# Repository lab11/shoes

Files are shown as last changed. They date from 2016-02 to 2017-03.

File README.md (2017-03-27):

Shoes!
======

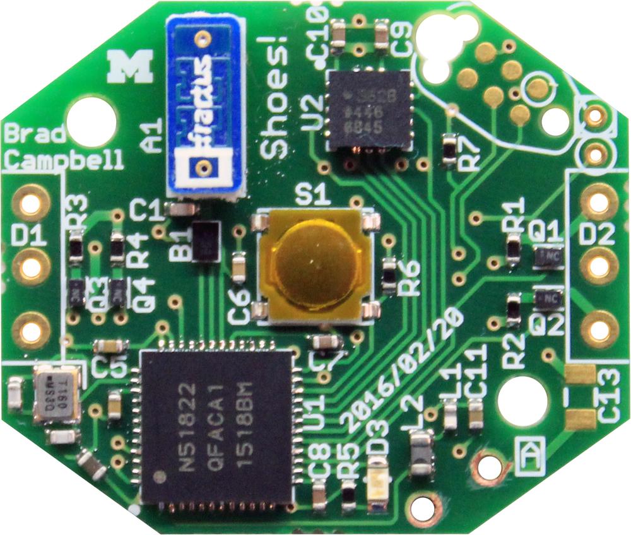
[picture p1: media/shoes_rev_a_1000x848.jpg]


BLE + shoelaces

Cloning This Repo
-----------------

When cloning this git repo, be sure to do so with submodules. The software
for this project depends on [nrf5x-base](https://github.com/lab11/nrf5x-base),
and to make sure you have the correct version of that repository, you need
to ensure that the submodule is checked out.

    git clone --recursive https://github.com/lab11/shoes.git

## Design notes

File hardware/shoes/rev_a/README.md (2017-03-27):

Shoes HW Rev A
==============

The shoes hardware PCB consists of:
- A Nordic nRF51822
- Two 2 color thru-hole LEDs
- A center push button
- An ADXL362 accelerometer

The nRF51822 BLE radio and processor is programmable over JTAG using the JLink JLinkExe program.
More information about programming the nRF51822 can he found
[here](https://github.com/lab11/nrf5x-base#program-a-nrf51822).

PCB Files
---------

The PCB was designed in [Eagle](http://www.autodesk.com/products/eagle/overview)
(version 6, but it should work in newer versions too.
Also committed are the gerbers that were used to manufacturer the first
revision of the boards.

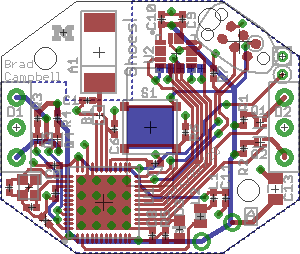
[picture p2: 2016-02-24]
hardware/shoes/rev_a/shoes_pcb.png

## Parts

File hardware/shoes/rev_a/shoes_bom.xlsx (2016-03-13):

Qty | Value | Device | Package | Parts | Description | DIGIKEY | MOUSER | NEWARK | RICHARDSON_RFPD |  | Quantity: |  | 100 | Quantity: |  | 250 | Quantity: |  | 400
1 | FRACTUS-2.4GHZ-FR05-S1-N-0-102 | FRACTUS-2.4GHZ-FR05-S1-N-0-102 | FRACTUS-ANTENNA-FR05-S1-N-0-102 | A1 | Fractus Compact Reach XtendTM chip antenna is engineered specifically for Bluetooth, |  |  |  | FR05-S1-N-0102B |  | 1 | 1 |  | 0.78 | 0.78 |  | 0.7 | 0.7
1 | BAL-NRF01D3 | BAL-NRF01D3 | BAL-NRF01D3 | B1 | 50 ohm nominal input / conjugate match balun to nRF51422-QFAA, | 497-13637-1-ND | 511-BAL-NRF01D3 |  |  |  | 0.52 | 0.52 |  | 0.52 | 0.52 |  | 0.52 | 0.52
1 | 0.8pF | CAPACITOR | 0402_CAP | C1 | 0402 Capacitor | 490-6269-1-ND |  |  |  |  | 0.0325 | 0.0325 |  | 0.02656 | 0.02656 |  | 0.02656 | 0.02656
2 | 12pF | CAPACITOR | 0402_CAP | C2, C3 | 0402 Capacitor | 490-6197-1-ND |  |  |  |  | 0.0198 | 0.0396 |  | 0.0162 | 0.0324 |  | 0.0162 | 0.0324
2 | 1nF | CAPACITOR | 0402_CAP | C4, C5 | 0402 Capacitor | 490-1303-1-ND |  |  |  |  | 0.0057 | 0.0114 |  | 0.00464 | 0.00928 |  | 0.00464 | 0.00928
1 | 2.2nF | CAPACITOR | 0402_CAP | C6 | 0402 Capacitor | 490-5419-1-ND |  |  |  |  | 0.0105 | 0.0105 |  | 0.00856 | 0.00856 |  | 0.00856 | 0.00856
1 | 47nF | CAPACITOR | 0402_CAP | C7 | 0402 Capacitor | 445-1264-1-ND |  |  |  |  | 0.0149 | 0.0149 |  | 0.01216 | 0.01216 |  | 0.01216 | 0.01216
3 | 0.1uF | CAPACITOR | 0402_CAP | C8, C9, C10 | 0402 Capacitor | 445-4952-1-ND |  |  |  |  | 0.0121 | 0.0363 |  | 0.00992 | 0.02976 |  | 0.00992 | 0.02976
1 | 1uF | CAPACITOR | 0402_CAP | C11 | 0402 Capacitor | 1276-1513-1-ND |  |  |  |  | 0.084 | 0.084 |  | 0.084 | 0.084 |  | 0.084 | 0.084
1 | 4.7uF | CAPACITOR | 0402_CAP | C12 | 0402 Capacitor | 445-5947-1-ND |  |  |  |  | 0.175 | 0.175 |  | 0.14 | 0.14 |  | 0.14 | 0.14
2 | BICOLOR-THRUHOLE | BICOLOR-THRUHOLE | 3AXIS-0.1IN | D1, D2 | 3 axis thru-hold LED |  |  |  |  |  | 1.28 | 2.56 |  | 1.18 | 2.36 |  | 0.98 | 1.96
1 | BLUE | LED0603 | LED-0603 | D3 | LEDs | 160-1837-1-ND |  |  |  |  | 0.1797 | 0.1797 |  | 0.12712 | 0.12712 |  | 0.12712 | 0.12712
1 | 15nH | INDUCTOR0402 | 0402_CAP | L1 |  | 587-1521-1-ND |  |  |  |  | 0.042 | 0.042 |  | 0.039 | 0.039 |  | 0.039 | 0.039
1 | 10uH | INDUCTOR0603 | 0603_CAP | L2 |  | 490-4025-1-ND |  |  |  |  | 0.0907 | 0.0907 |  | 0.08416 | 0.08416 |  | 0.08416 | 0.08416
4 | MOSFET-NCHANNELXFDN-3 | MOSFET-NCHANNELXFDN-3 | XFDFN-3 | Q1, Q2, Q3, Q4 | Generic NMOS footprint | DMN2400UFB4-7DICT-ND |  |  |  |  | 0.1585 | 0.634 |  | 0.1585 | 0.634 |  | 0.1585 | 0.634
4 | 470 | RESISTOR | 0402_RES | R1, R2, R3, R4 | Resistor | RHM470CDCT-ND |  |  |  |  | 0.0116 | 0.0464 |  | 0.00888 | 0.03552 |  | 0.00888 | 0.03552
2 | 1k | RESISTOR | 0402_RES | R5, R6 | Resistor | RHM1.0KCECT-ND |  |  |  |  | 0.0082 | 0.0164 |  | 0.00624 | 0.01248 |  | 0.00624 | 0.01248
1 | 12k | RESISTOR | 0402_RES | R7 | Resistor | RHM12.0KCDCT-ND |  |  |  |  | 0.0116 | 0.0116 |  | 0.00888 | 0.00888 |  | 0.00888 | 0.00888
1 | TL3315NF100Q | TL3315NF100Q | TL3315NF250Q | S1 | SWITCH TACTILE SPST-NO 0.05A 15V | EG4622CT-ND |  |  |  |  | 0.1823 | 0.1823 |  | 0.1716 | 0.1716 |  | 0.1716 | 0.1716
1 | NRF51822QF | NRF51822QF | QFN-48-6MM | U1 | Multiprotocol Bluetooth® 4.0 low energy/2.4 GHz RF SoC | 1490-1042-1-ND | 949-NRF51822-QFAC-R7 |  |  |  | 3.894 | 3.894 |  | 3.54 | 3.54 |  | 3.54 | 3.54
1 | ADXL362 | ADXL362 | TFLGA-16/3.3MMX3.1MM | U2 | IC ACCEL DIG LO PWR 3AX 16LGA | ADXL362BCCZ-RL7CT-ND | 584-ADXL362BCCZ-R7 | 47W0478 |  |  | 6.9018 | 6.9018 |  | 6.9018 | 6.9018 |  | 6.9018 | 6.9018
1 | 16MHz | TXC-8Y | TXC-8Y | X1 | 2mmx1.6mm SMD Crystal | 887-2003-1-ND |  |  |  |  | 0.945 | 0.945 |  | 0.945 | 0.945 |  | 0.945 | 0.945
1 | PCB |  |  |  |  |  |  |  |  |  | 4 | 4 |  | 3.2 | 3.2 |  | 2.5 | 2.5
1 | Assembly |  |  |  |  |  |  |  |  |  | 10 | 10 |  | 9 | 9 |  | 8 | 8
 |  |  |  |  |  |  |  |  |  | Parts Only |  | 17.4281 | $1742.81 |  | 16.50228 | $4125.57 |  | 16.02228 | $6408.91
 |  |  |  |  |  |  |  |  |  | Parts/PCB |  | 21.4281 | $2142.81 |  | 19.70228 | $4925.57 |  | 18.52228 | $7408.91
 |  |  |  |  |  |  |  |  |  | Parts/PCB/Assem |  | 31.4281 | $3142.81 |  | 28.70228 | $7175.57 |  | 26.52228 | $10608.91

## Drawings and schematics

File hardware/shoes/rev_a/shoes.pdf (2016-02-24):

## JTAG Connection

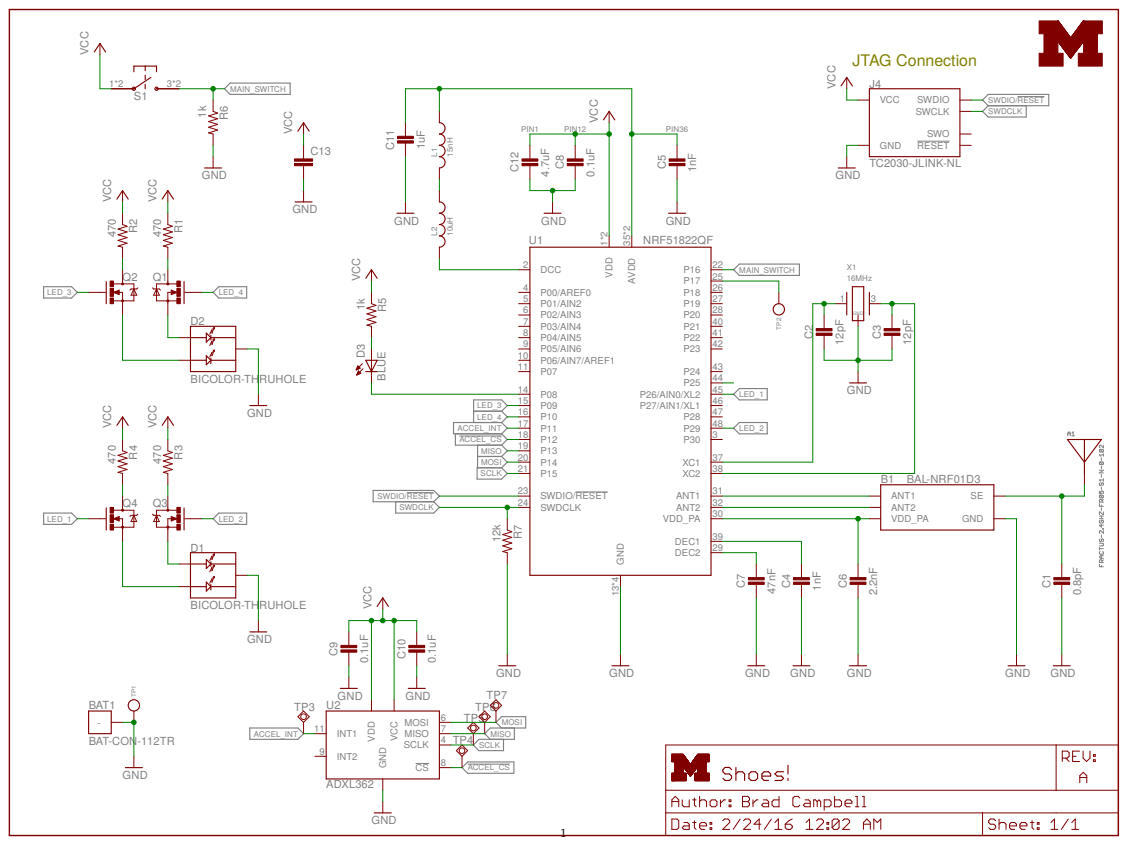
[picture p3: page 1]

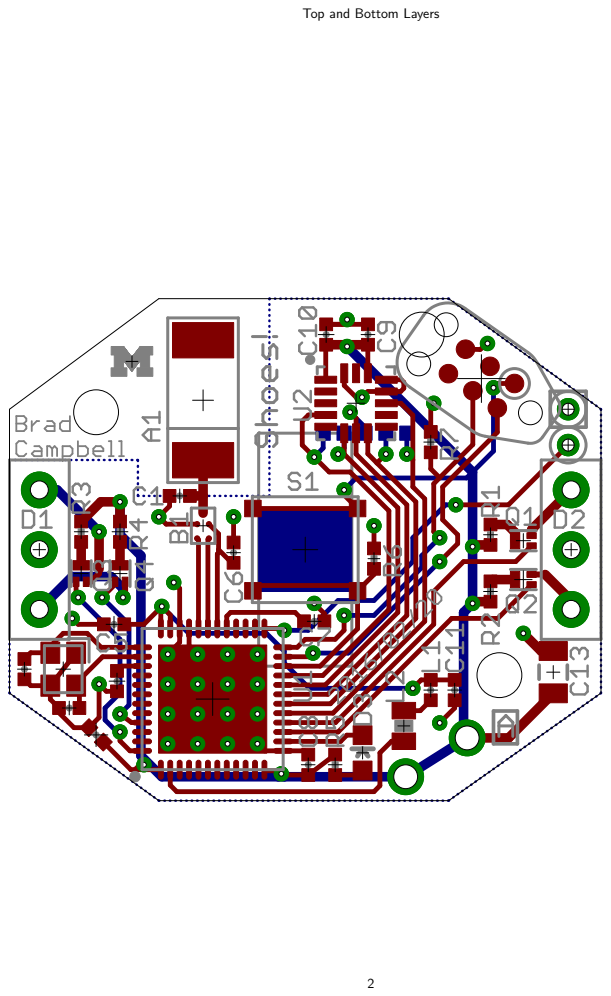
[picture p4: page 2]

Top and Bottom Layers

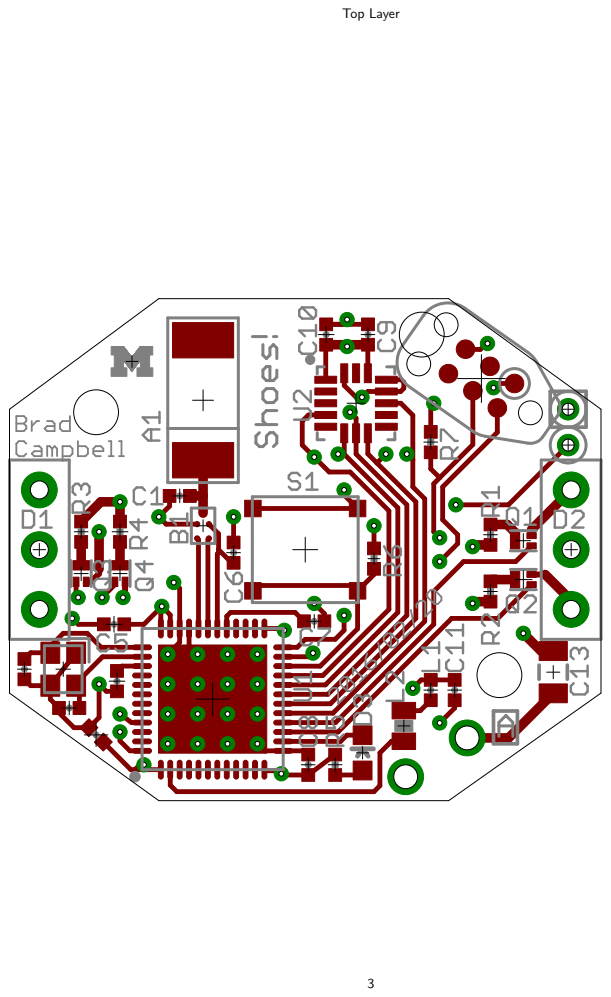
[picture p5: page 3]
Top Layer

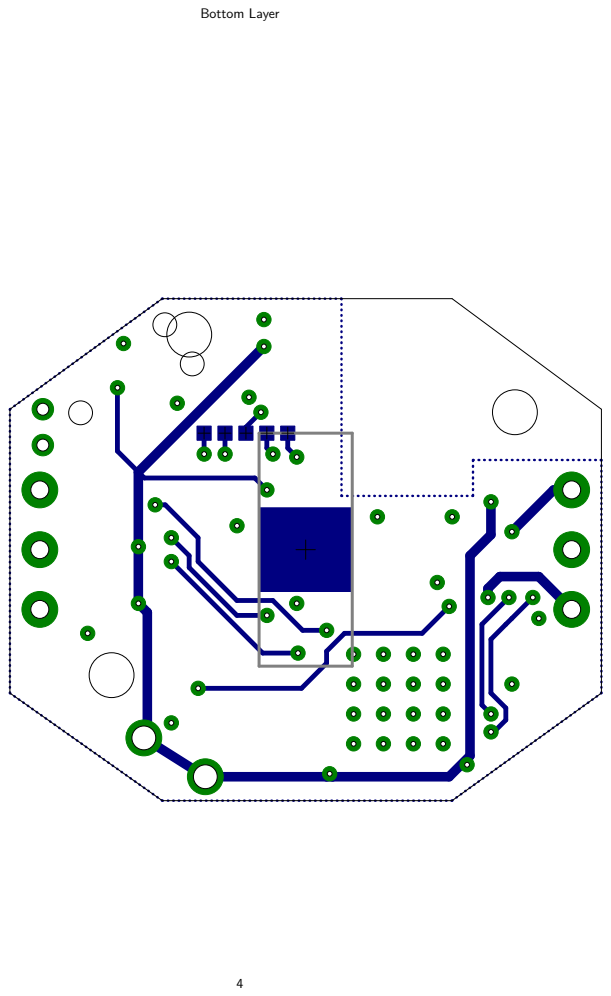
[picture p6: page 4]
Bottom Layer

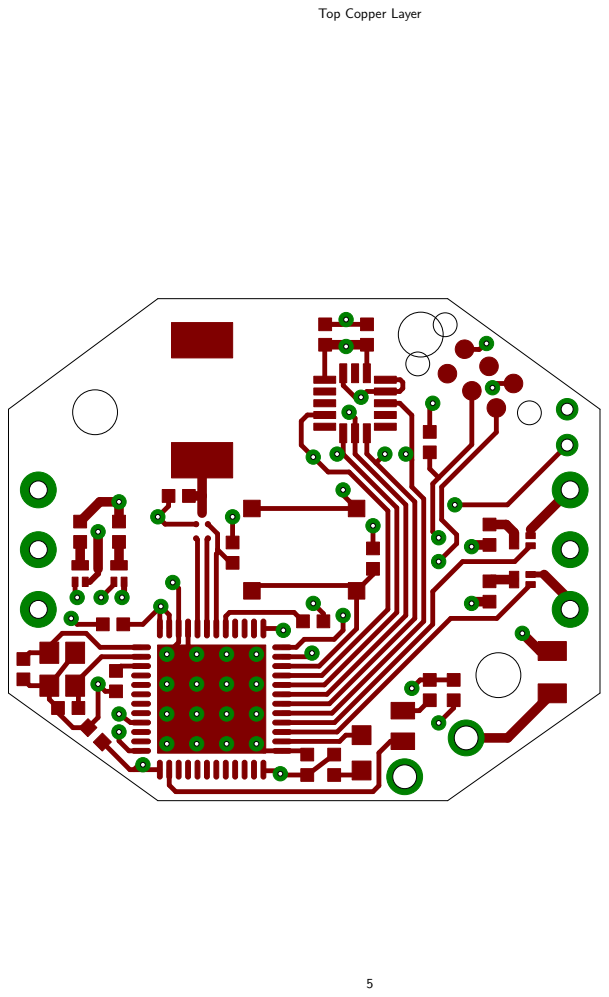
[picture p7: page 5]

Top Copper Layer

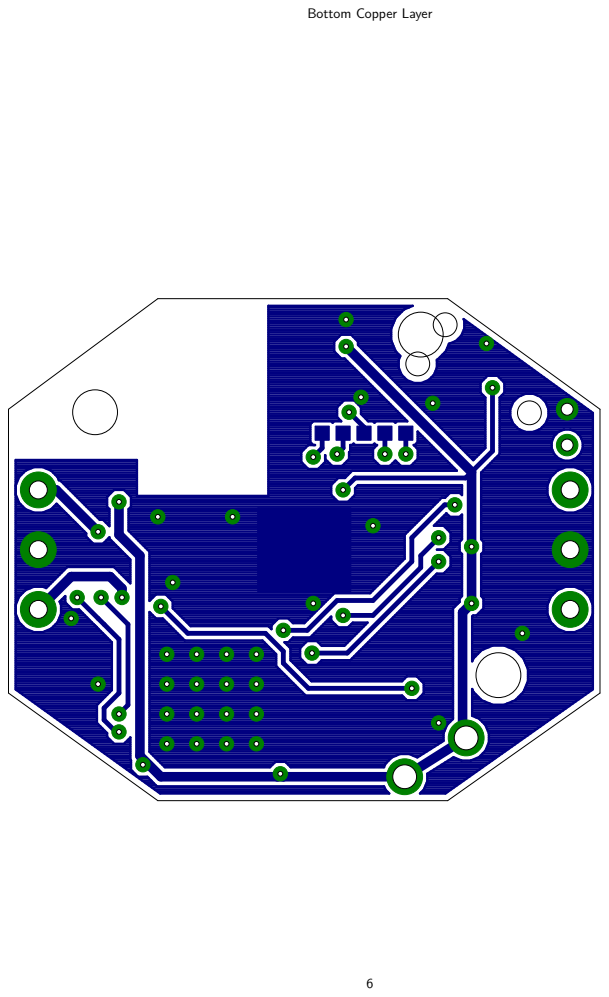
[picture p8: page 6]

Bottom Copper Layer

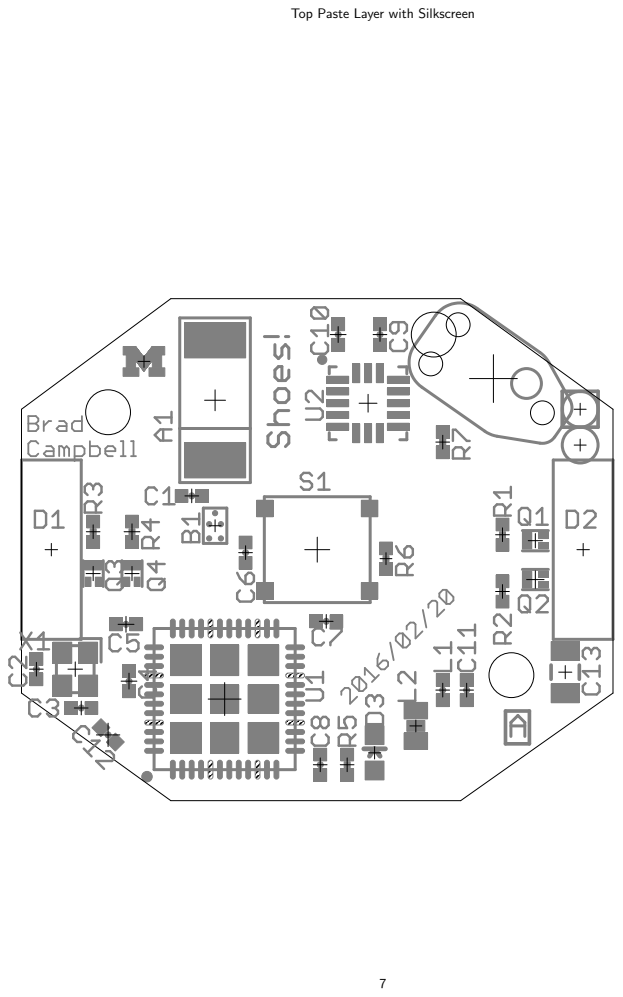
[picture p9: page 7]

Top Paste Layer with Silkscreen

Bottom Paste Layer with Silkscreen

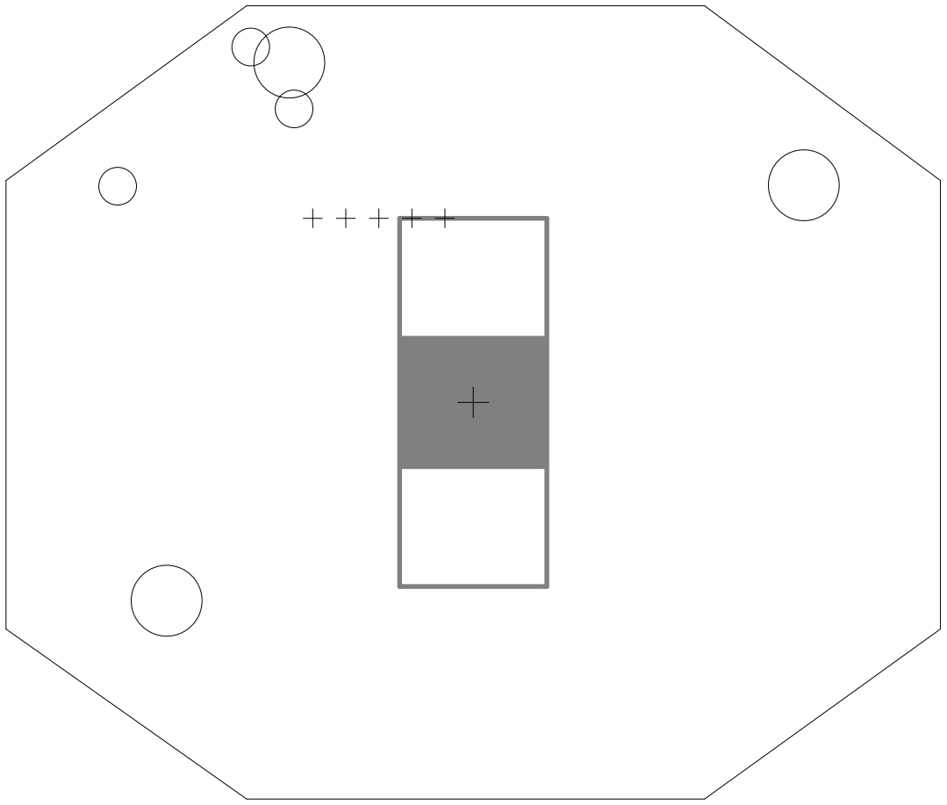
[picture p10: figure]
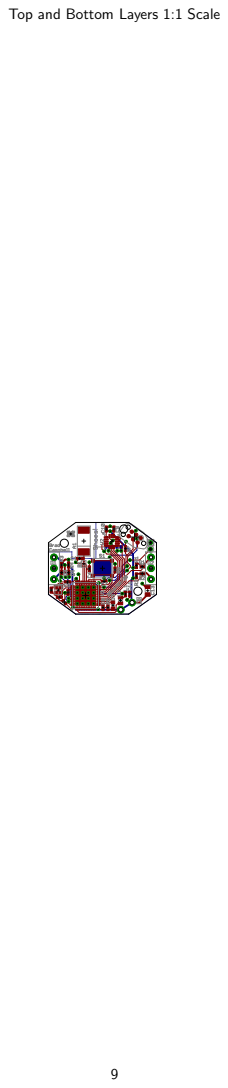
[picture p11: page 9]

Top and Bottom Layers 1:1 Scale

Top Layer 1:1 Scale

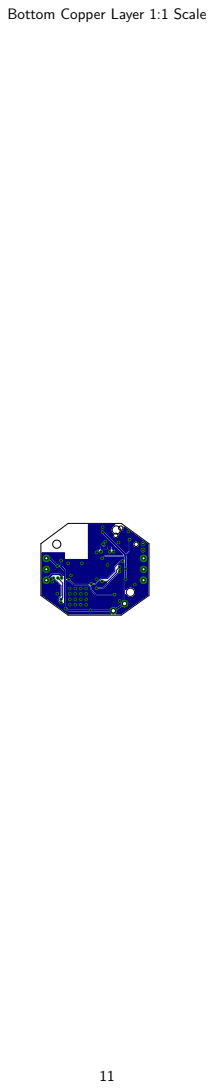
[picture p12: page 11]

Bottom Copper Layer 1:1 Scale

### shoes

Qty Value | Device
1 FRACTUS-2.4GHZ-FR05-S1-N-0-102 FRACTUS-2.4GHZ-FR05-S1-N-0-102
1 BAL-NRF01D3 | BAL-NRF01D3
1 0.8pF | CAPACITOR
2 12pF | CAPACITOR
2 1nF | CAPACITOR
1 2.2nF | CAPACITOR
1 47nF | CAPACITOR
3 0.1uF | CAPACITOR
1 1uF | CAPACITOR
1 4.7uF | CAPACITOR
2 BICOLOR-THRUHOLE | BICOLOR-THRUHOLE
1 BLUE | LED0603
1 15nH | INDUCTOR0402
1 10uH | INDUCTOR0603
4 MOSFET-NCHANNELXFDN-3 | MOSFET-NCHANNELXFDN-3
4 470 | RESISTOR
2 1k | RESISTOR
1 12k | RESISTOR
1 TL3315NF100Q | TL3315NF100Q
1 NRF51822QF | NRF51822QF
1 ADXL362 | ADXL362
1 16MHz | TXC-8Y

### shoes

Package | Parts
FRACTUS-ANTENNA-FR05-S1-N-0-102 A1
BAL-NRF01D3 | B1
0402_CAP | C1
0402_CAP | C2, C3
0402_CAP | C4, C5
0402_CAP | C6
0402_CAP | C7
0402_CAP | C8, C9, C10
0402_CAP | C11
0402_CAP | C12
3AXIS-0.1IN | D1, D2
LED-0603 | D3
0402_CAP | L1
0603_CAP | L2
XFDFN-3 | Q1, Q2, Q3, Q4
0402_RES | R1, R2, R3, R4
0402_RES | R5, R6
0402_RES | R7
TL3315NF100Q | S1
QFN-48-6MM | U1
TFLGA-16/3.3MMX3.1MM | U2
TXC-8Y | X1

### shoes

Description
Fractus Compact Reach XtendTM chip antenna is engineered specifically for Bluetooth, 50 ohm nominal input / conjugate match balun to nRF51422-QFAA,
0402 Capacitor
0402 Capacitor
0402 Capacitor
0402 Capacitor
0402 Capacitor
0402 Capacitor
0402 Capacitor
0402 Capacitor
3 axis thru-hold LED
LEDs

Generic NMOS footprint
Resistor
Resistor
Resistor
SWITCH TACTILE SPST-NO 0.05A 15V Multiprotocol Bluetooth® 4.0 low energy/2.4 GHz RF SoC IC ACCEL DIG LO PWR 3AX 16LGA
2mmx1.6mm SMD Crystal

### shoes

DIGIKEY | MOUSER | NEWARK RICHARDSON_RFPD
| | FR05-S1-N-0102B
497-13637-1-ND | 511-BAL-NRF01D3
490-6269-1-ND
490-6197-1-ND
490-1303-1-ND
490-5419-1-ND
445-1264-1-ND
445-4952-1-ND
1276-1513-1-ND
445-5947-1-ND

587-1521-1-ND
490-4025-1-ND
DMN2400UFB4-7DICT-ND
RHM470CDCT-ND
RHM1.0KCECT-ND
RHM12.0KCDCT-ND
EG4620CT-ND
1490-1042-1-ND | 949-NRF51822-QFAC-R7
ADXL362BCCZ-RL7CT-ND 584-ADXL362BCCZ-R7 47W0478 887-2003-1-ND

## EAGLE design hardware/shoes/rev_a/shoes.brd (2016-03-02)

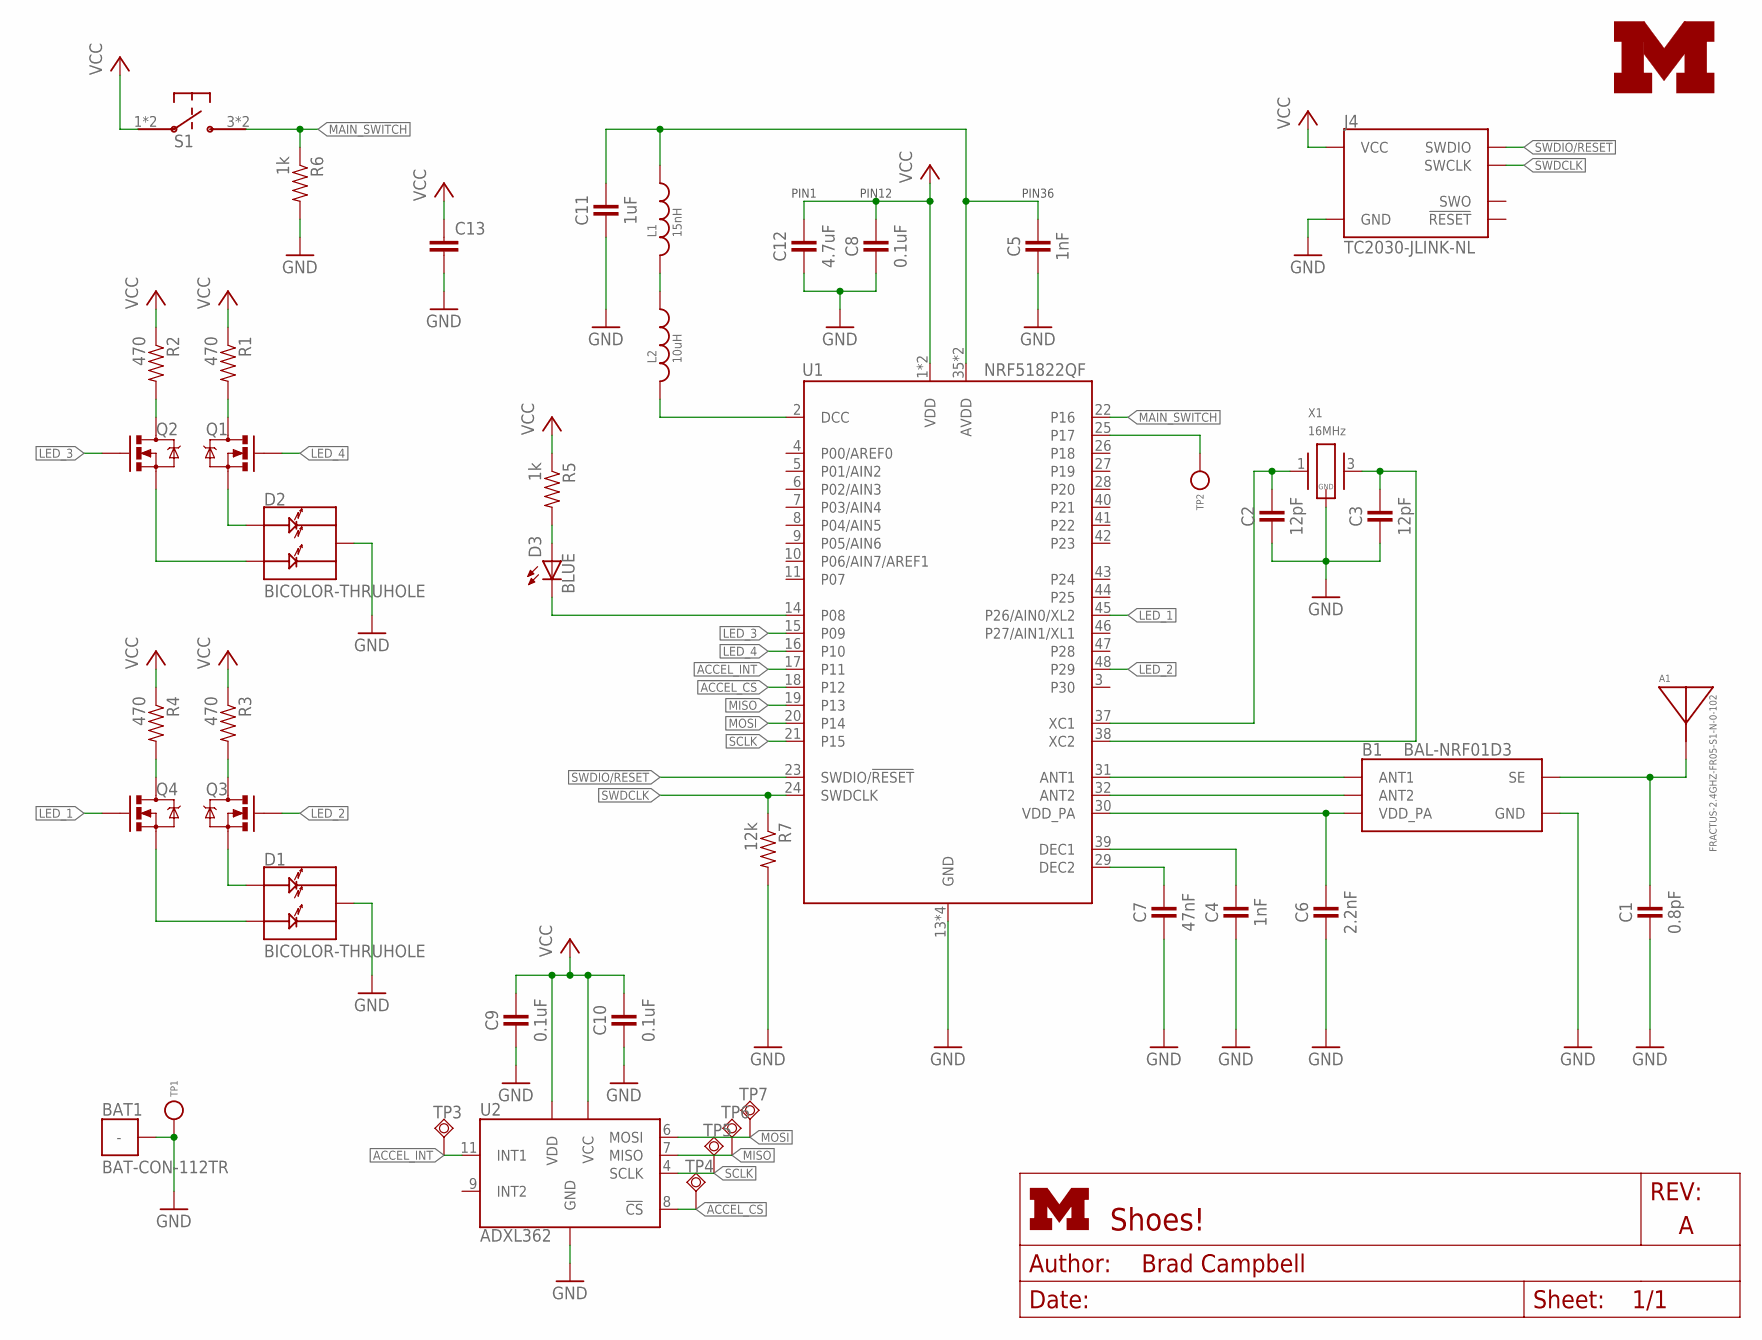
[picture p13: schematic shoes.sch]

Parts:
A1: FRACTUS-2.4GHZ-FR05-S1-N-0-102; FRACTUS-ANTENNA-FR05-S1-N-0-102
B1: BAL-NRF01D3
BAT1: BAT-CON-112TR
C1: 0.8pF; 0402_CAP; DIGIKEY 490-6269-1-ND
C2, C3: 12pF; 0402_CAP; DIGIKEY 490-6197-1-ND
C4, C5: 1nF; 0402_CAP; DIGIKEY 490-1303-1-ND
C6: 2.2nF; 0402_CAP; DIGIKEY 490-5419-1-ND
C7: 47nF; 0402_CAP; DIGIKEY 445-1264-1-ND
C8, C9, C10: 0.1uF; 0402_CAP; DIGIKEY 445-4952-1-ND
C11: 1uF; 0402_CAP; DIGIKEY 1276-1513-1-ND
C12: 4.7uF; 0402_CAP; DIGIKEY 445-5947-1-ND
C13: CAP0805; 0805
D1, D2: BICOLOR-THRUHOLE; 3AXIS-0.1IN
D3: BLUE; LED-0603
J4: TC2030-JLINK-NL; TC2030-IDC-NL
L1: 15nH; 0402_CAP; DIGIKEY 587-1521-1-ND
L2: 10uH; 0603_CAP; DIGIKEY 490-4025-1-ND
LOGO3: UMICH_SOLID_TINY; UMICH_SOLID_50MIL
Q1, Q2, Q3, Q4: MOSFET-NCHANNELXFDN-3; XFDFN-3
R1, R2, R3, R4: 470; 0402_RES; DIGIKEY RHM470CDCT-ND
R5, R6: 1k; 0402_RES; DIGIKEY RHM1.0KCECT-ND
R7: 12k; 0402_RES; DIGIKEY RHM12.0KCDCT-ND
S1: TL3315NF100Q
TP1, TP2: TEST_POINT_0.020IN; TESTPOINT_0.020IN
TP3, TP4, TP5, TP6, TP7: TPSQTP06SQ; TP06SQ
U1: NRF51822QF; QFN-48-6MM
U2: ADXL362; TFLGA-16/3.3MMX3.1MM
X1: 16MHz; TXC-8Y; DIGIKEY 887-2003-1-ND

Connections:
!ACCEL_CS: TP4.TP, U1.18 (P12), U2.8 (!CS)
ACCEL_INT: TP3.TP, U1.17 (P11), U2.11 (INT1)
AVDD: C5.1, C11.1, L1.1, U1.35 (AVDD), U1.36 (AVDD)
DCC: L2.2, U1.2 (DCC)
GND: B1.GND, BAT1.PAD, C1.2, C2.2, C3.2, C4.2, C5.2, C6.2, C7.2, C8.2, C9.2, C10.2, C11.2, C12.2, C13.2, D1.M (C), D2.M (C), J4.5 (GND), R6.2, R7.2, TP1.TESTPOINT, U1.13 (GND), U1.33 (GND), U1.34 (GND), U1.GND, U2.12 (GND), U2.13 (GND), U2.16 (GND), X1.2 (GND), X1.4 (GND)
LED_1: Q4.G, U1.45 (P26/AIN0/XL2)
LED_2: Q3.G, U1.48 (P29)
LED_3: Q2.G, U1.15 (P09)
LED_4: Q1.G, U1.16 (P10)
MAIN_SWITCH: R6.1, S1.3, S1.4, U1.22 (P16)
MISO: TP6.TP, U1.19 (P13), U2.7 (MISO)
MOSI: TP7.TP, U1.20 (P14), U2.6 (MOSI)
unnamed: TP2.TESTPOINT, U1.25 (P17)
unnamed: D2.1 (A1), Q1.S
unnamed: B1.ANT1, U1.31 (ANT1)
unnamed: B1.ANT2, U1.32 (ANT2)
unnamed: D3.C, U1.14 (P08)
unnamed: D2.2 (A2), Q2.S
unnamed: Q2.D, R2.2
unnamed: Q1.D, R1.2
unnamed: A1.1, B1.SE, C1.1
unnamed: D1.1 (A1), Q3.S
unnamed: D1.2 (A2), Q4.S
unnamed: L1.2, L2.1
unnamed: Q4.D, R4.2
unnamed: C2.1, U1.37 (XC1), X1.1
unnamed: C3.1, U1.38 (XC2), X1.3 (2)
unnamed: C4.1, U1.39 (DEC1)
unnamed: C7.1, U1.29 (DEC2)
unnamed: Q3.D, R3.2
unnamed: D3.A, R5.2
SCLK: TP5.TP, U1.21 (P15), U2.4 (SCLK)
SWDCLK: J4.4 (SWCLK), R7.1, U1.24 (SWDCLK)
SWDIO/!RESET: J4.2 (SWDIO), U1.23 (SWDIO/!RESET)
VCC: C8.1, C9.1, C10.1, C12.1, C13.1, J4.1 (VCC), R1.1, R2.1, R3.1, R4.1, R5.1, S1.1, S1.2, U1.1 (VDD), U1.12 (VDD), U2.1 (VDD), U2.14 (VCC)
VDD_PA: B1.VCC (VDD_PA), C6.1, U1.30 (VDD_PA)

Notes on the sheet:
PIN12
PIN1
PIN36

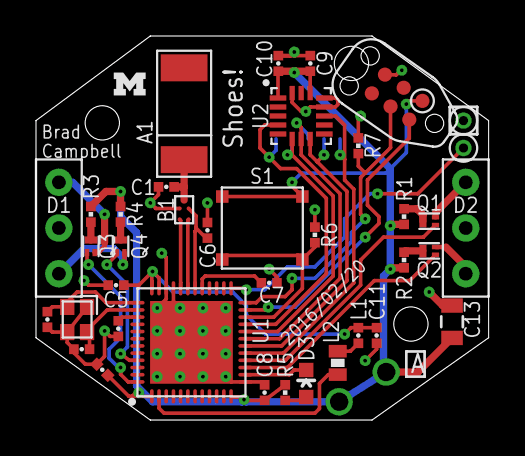
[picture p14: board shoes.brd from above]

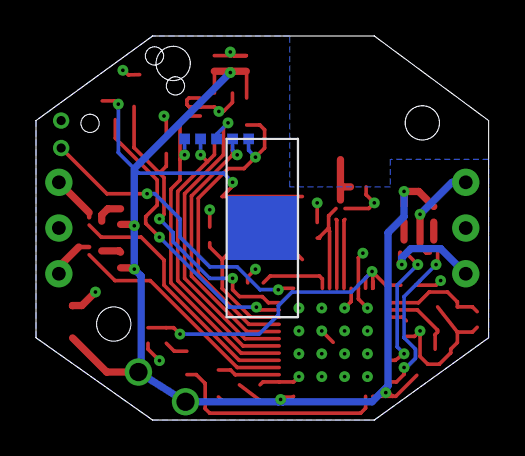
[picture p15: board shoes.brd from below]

Board: 2 copper layers, 25.1 x 21.3 mm, 45 parts (6 on the bottom side), 36 nets.

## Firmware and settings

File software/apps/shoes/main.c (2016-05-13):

#include <stdint.h>
#include <string.h>

#include "nordic_common.h"
#include "nrf.h"
#include "nrf_soc.h"
#include "app_error.h"
#include "softdevice_handler.h"
#include "app_timer.h"
#include "app_button.h"
#include "app_util.h"
#include "nrf_drv_spi.h"
#include "nrf_drv_rng.h"
#include "app_gpiote.h"
#include "nrf_delay.h"

#include "bootloader_types.h"
#include "bootloader_util.h"

#include "radio.h"

#include "led.h"
#include "adxl362.h"
#include "board.h"


/******************************************************************************/
/* Configuration
 ******************************************************************************/

#define DEVICE_NAME "Shoes!"

// Setup how we want the timeslots to work (taking the radio from the
// softdevice).
#define TIMESLOT_LENGTH_US   100000
#define TIMESLOT_DISTANCE_US 100000
#define TIMESLOT_TIMEOUT_US 200000

// How long the light should stay on for the flood
#define FLOOD_LED_TIME_MS 5000
#define FLOOD_TIMESLOT_MS 300

// Something for button API
#define BUTTON_DETECTION_DELAY   APP_TIMER_TICKS(50, 0)

// How long a long press is defined to be, in ms
#define BUTTON_LONG_PRESS_LENGTH APP_TIMER_TICKS(1500, 0)

// // How long before we have not seen a flood recently
// #define FLOOD_RECENT_TIME APP_TIMER_TICKS(1000, 0)

// Types of packets in the Shoes! protocol
#define SHOES_PKT_TYPE_FLOOD 0x01  // Start or continue a flood

// How many times to send a packet announcing this flood
#define NUMBER_OF_FLOOD_TRANSMISSIONS 8

// Pin defines
#define LED0 8
#define LED1 26
#define LED2 29
#define LED3 9
#define LED4 10

#define ACCELEROMETER_INTERRUPT_PIN 11
#define BUTTON_INTERRUPT_PIN 16


/******************************************************************************/
/* Global state
 ******************************************************************************/

// SPI bus for accelerometer
static nrf_drv_spi_t _spi = NRF_DRV_SPI_INSTANCE(SPI_INSTANCE);

// Struct for getting GPIO interrupts
static app_gpiote_user_id_t gpiote_user_acc;

// Structs for calling the timeslot APIs
static nrf_radio_signal_callback_return_param_t m_signal_callback_return_param;
static nrf_radio_request_t m_timeslot_req_earliest = {
    NRF_RADIO_REQ_TYPE_EARLIEST,
    .params.earliest = {
        NRF_RADIO_HFCLK_CFG_NO_GUARANTEE,
        NRF_RADIO_PRIORITY_NORMAL,
        TIMESLOT_LENGTH_US,
        TIMESLOT_TIMEOUT_US
    }
};

// Timer for delaying packet re-transmissions
APP_TIMER_DEF(timer_flood_tx);

// Timer for going back to idle after a flood has started
APP_TIMER_DEF(timer_flood_led);

// Timer that lets us monitor how long its been since we joined a flood.
// We use this for activating the third color when two floods intersect.
// APP_TIMER_DEF(timer_flood_recent);

// Keep track of unique flood id for this node
static uint8_t _my_flood_counter = 0;

// How many floods we are currently seeing
// static uint8_t _current_flood_count = 0;

// Advertisement packet structure
#define RX_BUF_SIZE 128
static uint8_t m_rx_buf[RX_BUF_SIZE];

typedef struct {
    uint8_t length;
    uint8_t type;
    uint8_t man_id1;
    uint8_t man_id2;
    uint8_t service_id;
    uint8_t packet_type;
    // uint8_t data[5];
    uint8_t data[8];
    // uint8_t data[4];
} __attribute__((packed)) shoes_manuf_data_t;

typedef struct {
    uint8_t type_and_options;
    uint8_t length;
    uint8_t s1;
    uint8_t src_addr[6];
    uint8_t flags[3];
    shoes_manuf_data_t manuf;
    uint8_t name[8];
} __attribute__((packed)) advertisement_t;


advertisement_t advertisement = {
    .type_and_options = 0x02,  // ADV_NONCONN_IND
    // .type_and_options = 0x00,  // ADV_NONCONN_IND
    // .length = 28,
    .length = 31,
    // .length = 27,
    .s1 = 0,
    .src_addr = {0x00, 0x00, 0x00, 0xe5, 0x98, 0xc0},
    .flags = {0x02, 0x01, 0x06},
    .manuf = {
        // .length = 9,
        // .length = 10,
        .length = 13,
        .type = 0xff,
        .man_id1 = 0xe0,
        .man_id2 = 0x02,
        .service_id = 0x14,
        .packet_type = 0,
        .data = {0, 0, 0, 0, 0, 0, 0, 0}},
        // .data = {0, 0, 0, 0, 0}},
        // .data = {0, 0, 0, 0}},
    .name = {7, 0x09, 0x53, 0x48, 0x4f, 0x45, 0x53, 0x21}
};


typedef enum {
    STATE_OFF,
    STATE_COLOR1,
    STATE_COLOR2
} shoes_state_e;

// Board defaults to on
static shoes_state_e _shoes_state = STATE_COLOR1;

// Which color our floods will be.
static int _my_color = 1;

// State for setting up the button
static void button_handler (uint8_t button, uint8_t action);
static app_button_cfg_t buttons[] = {
    {BUTTON_INTERRUPT_PIN, APP_BUTTON_ACTIVE_HIGH, NRF_GPIO_PIN_NOPULL, button_handler}
};

// Timer for measuring button press event length
APP_TIMER_DEF(timer_button_press);

// After a long button press we may want to ignore the button release
static bool _ignore_button_release = false;

// We want to send duplicate packets to get better flooding
static uint8_t _transmit_count = 0;

typedef enum {
    LED_STATE_OFF,
    LED_STATE_ON
} led_state_e;

static led_state_e _led_state = LED_STATE_OFF;

// What color we should be
static uint8_t _flood_color;

// When we got the packet telling us a flood was happening
static uint32_t _flood_timing_start;

// Whether we have seen a flood recently.
static bool _in_flood = false;

// How long to wait before turning off LED
static uint32_t _flood_off_time_ticks = 0;

/*******************************************************************************
 * Function signatures
 ******************************************************************************/

void timeslot_sys_event_handler (uint32_t evt);


/*******************************************************************************
 * Error callbacks
 ******************************************************************************/

void ble_error (uint32_t error_code) {
    led_on(LED0);
}

void assert_nrf_callback (uint16_t line_num, const uint8_t * p_file_name) {
    led_on(LED0);
    app_error_handler(0x5599, line_num, p_file_name);
}


/*******************************************************************************
 * DFU Helper Stuff
 ******************************************************************************/

#define IRQ_ENABLED               0x01
#define MAX_NUMBER_INTERRUPTS     32
#define BOOTLOADER_BLE_ADDR_START 0x20007F80

static void interrupts_disable(void) {
    uint32_t interrupt_setting_mask;
    uint32_t irq = 0; // We start from first interrupt, i.e. interrupt 0.

    // Fetch the current interrupt settings.
    interrupt_setting_mask = NVIC->ISER[0];

    for (; irq < MAX_NUMBER_INTERRUPTS; irq++) {
        if (interrupt_setting_mask & (IRQ_ENABLED << irq)) {
            // The interrupt was enabled, and hence disable it.
            NVIC_DisableIRQ((IRQn_Type)irq);
        }
    }
}

bool pending_dfu = false;


/*******************************************************************************
 * System functions
 ******************************************************************************/

static void on_ble_evt(ble_evt_t * p_ble_evt) {
    switch (p_ble_evt->header.evt_id) {
        case BLE_GAP_EVT_CONNECTED:
        case BLE_GAP_EVT_DISCONNECTED:
        case BLE_GAP_EVT_TIMEOUT:
        case BLE_GATTC_EVT_TIMEOUT:
        case BLE_GATTS_EVT_TIMEOUT:
            break;

        default:
            break;
    }
}

static void ble_evt_dispatch (ble_evt_t * p_ble_evt) {
    on_ble_evt(p_ble_evt);
}

static void sys_evt_dispatch (uint32_t sys_evt) {
    timeslot_sys_event_handler(sys_evt);
}

// Function for the Power manager.
static void power_manage (void) {
    uint32_t err_code = sd_app_evt_wait();
    APP_ERROR_CHECK(err_code);
}

void dfu_reset_prepare (void) {
    // Disable the interrupts!
    app_gpiote_user_disable(gpiote_user_acc);

    // reset accelerometer
    adxl362_accelerometer_reset();
}

void timeslot_sys_event_handler (uint32_t evt) {
    uint32_t err_code;

    switch (evt) {
      case NRF_EVT_RADIO_SESSION_IDLE:
      case NRF_EVT_RADIO_BLOCKED:
        // If we ever get here, we canceled our timeslots. This could mean
        // we want to go to the bootloader, or this could me we turned off
        sd_radio_session_close();
        break;

      case NRF_EVT_RADIO_SESSION_CLOSED: {

            // If we get to session closed, we may want to enter the bootloader
            if (pending_dfu) {
                dfu_reset_prepare();

                // These steps from dfu_app_handler.c
                err_code = sd_power_gpregret_set(BOOTLOADER_DFU_START);
                APP_ERROR_CHECK(err_code);

                err_code = sd_softdevice_disable();
                APP_ERROR_CHECK(err_code);

                err_code = sd_softdevice_vector_table_base_set(NRF_UICR->BOOTLOADERADDR);
                APP_ERROR_CHECK(err_code);

                NVIC_ClearPendingIRQ(SWI2_IRQn);
                interrupts_disable();

                bootloader_util_app_start(NRF_UICR->BOOTLOADERADDR);
            }

            break;
        }

      case NRF_EVT_RADIO_SIGNAL_CALLBACK_INVALID_RETURN:
        // ASSERT(false);
        break;

      case NRF_EVT_RADIO_CANCELED:
        err_code = sd_radio_request(&m_timeslot_req_earliest);
        APP_ERROR_CHECK(err_code);
        break;

      default:
        break;
    }
}



/*******************************************************************************
 * Control the radio
 ******************************************************************************/

static void continue_scan () {
    radio_disable();

    memset((void*) m_rx_buf, '\0', RX_BUF_SIZE);
    radio_buffer_configure(&m_rx_buf[0]);
    radio_rx_prepare(true);
    radio_rssi_enable();
}


static void start_scan () {
    NVIC_EnableIRQ(TIMER0_IRQn);

    radio_init(37); // set channel to only use 37. Makes BLE scanner work well.
    radio_rx_timeout_init();

    continue_scan();
}


static uint16_t ticks_to_ms (uint32_t ticks) {
    return (uint16_t) ((ticks * ((0 + 1 ) * 1000)) / APP_TIMER_CLOCK_FREQ);
}


static void send_advertisement () {
    uint32_t now;
    uint32_t diff;

    // Increment how many packets we have sent propagating this flood.
    _transmit_count++;

    // Get current count so we know when this packet actually went out
    app_timer_cnt_get(&now);
    app_timer_cnt_diff_compute(now, _flood_timing_start, &diff);

    // Insert the ms offset into the outgoing packet
    uint16_t offset = ticks_to_ms(diff);
    advertisement.manuf.data[3] = offset & 0xFF;
    advertisement.manuf.data[4] = (offset >> 8) & 0xFF;

    radio_disable();
    radio_init(37); // set channel to only use 37
    radio_buffer_configure((uint8_t*) &advertisement);
    radio_tx_prepare();
}





/*******************************************************************************
 * Keep track of a little bit of history
 ******************************************************************************/

// Circular buffers to keep track of recent floods.
// We keep more than one because it's conceivable we get a packet about
// a flood that we have already completed.
#define KNOWN_FLOOD_BUFFER_LEN 10
uint32_t known_flood_initiators[KNOWN_FLOOD_BUFFER_LEN] = {0};
uint8_t known_flood_initiators_ids[KNOWN_FLOOD_BUFFER_LEN] = {0};
uint8_t known_flood_head = 0;

static bool flood_id_is_new (uint32_t id, uint8_t flood_id) {
    uint8_t i;

    for (i=0; i<KNOWN_FLOOD_BUFFER_LEN; i++) {
        if (known_flood_initiators[i] == id &&
            known_flood_initiators_ids[i] == flood_id) {
            // If we find the given flood initiator and flood id in the
            // stored values then we have seen this before
            return false;
        }
    }
    return true;
}

static void flood_id_record (uint32_t id, uint8_t flood_id) {
    uint8_t i;
    bool updated = false;

    for (i=0; i<KNOWN_FLOOD_BUFFER_LEN; i++) {
        if (known_flood_initiators[i] == id) {
            // Hey! we are already in the buffer store. Just update
            // the flood id
            known_flood_initiators_ids[i] = flood_id;
            updated = true;
            break;
        }
    }

    if (!updated) {
        // We couldn't find this id in our buffer, so we must add it.
        known_flood_initiators[known_flood_head] = id;
        known_flood_initiators_ids[known_flood_head] = flood_id;
        known_flood_head = (known_flood_head + 1) % KNOWN_FLOOD_BUFFER_LEN;
    }
}


/*******************************************************************************
 * Flooding functions
 ******************************************************************************/

static void leds_off () {
    led_on(LED1);
    led_on(LED3);
    led_on(LED2);
    led_on(LED4);
}

static void leds_color1 () {
    led_off(LED2);
    led_off(LED4);
    led_on(LED1);
    led_on(LED3);
}

static void leds_color2 () {
    led_off(LED1);
    led_off(LED3);
    led_on(LED2);
    led_on(LED4);
}

static void leds_both () {
    led_off(LED1);
    led_off(LED3);
    led_off(LED2);
    led_off(LED4);
}

static void ui_off () {
    // Turn all LEDs on
    led_on(LED0);
    leds_both();
    nrf_delay_ms(500);

    // Turn off one side
    led_on(LED1);
    led_on(LED2);
    nrf_delay_ms(500);

    // Turn off other side
    led_on(LED3);
    led_on(LED4);
    nrf_delay_ms(500);

    // Turn off blue
    led_off(LED0);
}

static void ui_color1 () {
    leds_color1();
    nrf_delay_ms(1000);
    leds_off();
}

static void ui_color2 () {
    leds_color2();
    nrf_delay_ms(1000);
    leds_off();
}

static void leds_flood (uint8_t _flood_color) {
    if      (_flood_color == 1) leds_color1();
    else if (_flood_color == 2) leds_color2();
    else if (_flood_color == 3) leds_both();
}

static void start_flood () {

    // Since we started this flood, the flood color is our color
    _flood_color = _my_color;

    // Mark this as a flood
    advertisement.manuf.packet_type = SHOES_PKT_TYPE_FLOOD;
    _my_flood_counter++;
    advertisement.manuf.data[0] = _my_flood_counter;
    // Keep track of which hop this is
    advertisement.manuf.data[1] = 0;
    // // Also transmit which color we are
    advertisement.manuf.data[2] = _my_color;
    // Also include that we are the ones who started it
    advertisement.manuf.data[5] = advertisement.src_addr[2];
    advertisement.manuf.data[6] = advertisement.src_addr[1];
    advertisement.manuf.data[7] = advertisement.src_addr[0];

    // Mark that we are in a flood
    _in_flood = true;

    // // Set a timer to timeout the _in_flood variable
    // app_timer_stop(timer_flood_recent);
    // app_timer_start(timer_flood_recent, FLOOD_RECENT_TIME, NULL);

    // Decide when to turn our LED off.
    // Since we started the flood, we wait the full time
    _flood_off_time_ticks = APP_TIMER_TICKS(FLOOD_LED_TIME_MS, 0);

    // We set our LED immediately when we start a flood, but we still
    // want a timer so we can put this logic in the same place
    // for all nodes.
    app_timer_stop(timer_flood_led);
    app_timer_start(timer_flood_led, APP_TIMER_TICKS(2, 0), NULL);
}

static void join_flood (int8_t rssi, uint32_t initiator_id, uint8_t flood_id, uint8_t hop_count, uint8_t color, uint16_t delay) {

    // If we are already using third color, use that
    _flood_color = color;
    // If we have seen a flood recently, also use third color
    if (_in_flood) {
        _flood_color = 3;
    }

    // Mark that we are in a flood
    _in_flood = true;

    // // Set a timer to timeout the _in_flood variable
    // app_timer_stop(timer_flood_recent);
    // app_timer_start(timer_flood_recent, FLOOD_RECENT_TIME, NULL);

    // Calculate when to turn off our LED
    _flood_off_time_ticks = APP_TIMER_TICKS(FLOOD_LED_TIME_MS-(((hop_count+1)%15) * FLOOD_TIMESLOT_MS), 0);

    // We don't set our LEDs for FLOOD_TIMESLOT_MS ms from when this flood round started
    app_timer_stop(timer_flood_led);
    app_timer_start(timer_flood_led, APP_TIMER_TICKS(FLOOD_TIMESLOT_MS-delay, 0), NULL);

    // Mark this as a flood
    advertisement.manuf.packet_type = SHOES_PKT_TYPE_FLOOD;
    // _my_flood_counter++;
    advertisement.manuf.data[0] = flood_id;
    // Keep track of which hop this is
    advertisement.manuf.data[1] = hop_count+1;
    // // Also transmit which color we are
    advertisement.manuf.data[2] = color;
    // Also include the node that started this particular flood
    advertisement.manuf.data[5] = (initiator_id >> 16) & 0xFF;
    advertisement.manuf.data[6] = (initiator_id >> 8)  & 0xFF;
    advertisement.manuf.data[7] = (initiator_id >> 0)  & 0xFF;
}

// Send a flood packet some time in the future
static void send_flood_message () {
    uint8_t random = 5;
    random = NRF_RNG->VALUE;

    random = (random & 0x1f); // cap at 31
    if (random < 5) {
        random = 5;
    }

    app_timer_stop(timer_flood_tx);
    app_timer_start(timer_flood_tx, APP_TIMER_TICKS(random, 0), NULL);
}


/*******************************************************************************
 * Callbacks
 ******************************************************************************/
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
int main () {
    // Initialize.
    led_init(LED0);
    led_off(LED0);

    // These are active high...go figure
    led_init(LED1);
    led_init(LED2);
    led_init(LED3);
    led_init(LED4);
    leds_off();

    // Essentially initialize soft device
    ble_stack_init();

    // Copy BLE address into our outgoing advertisement struct
    memcpy(advertisement.src_addr, (uint8_t*) BLEADDR_FLASH_LOCATION, 6);

    // Need to init timer system
    APP_TIMER_INIT(0, // prescaler
                   4, // op queue size
                   false);
    // Create the one-shot timers
    app_timer_create(&timer_flood_tx, APP_TIMER_MODE_SINGLE_SHOT, timer_flood_tx_callback);
    app_timer_create(&timer_flood_led, APP_TIMER_MODE_SINGLE_SHOT, timer_flood_led_callback);
    // app_timer_create(&timer_flood_recent, APP_TIMER_MODE_SINGLE_SHOT, timer_flood_recent_callback);

    // Use nordics button api
    app_button_init(buttons, 1, BUTTON_DETECTION_DELAY);
    app_button_enable();
    // Need to time the button press
    app_timer_create(&timer_button_press, APP_TIMER_MODE_SINGLE_SHOT, timer_button_press_callback);

    // Need to setup our accelerometer
    accelerometer_init();

    // Want random ish numbers to delay packet transmission
    uint32_t err_code = nrf_drv_rng_init(NULL);
    if (err_code !=NRF_SUCCESS) {
        led_on(LED0);
    }

    // Init to on
    sd_radio_session_open(radio_cb);
    sd_radio_request(&m_timeslot_req_earliest);

    // Enter main loop and essentially wait for button press
    while (1) {
        power_manage();
    }
}

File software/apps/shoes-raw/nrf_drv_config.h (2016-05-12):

/* Copyright (c) 2015 Nordic Semiconductor. All Rights Reserved.
 *
 * The information contained herein is property of Nordic Semiconductor ASA.
 * Terms and conditions of usage are described in detail in NORDIC
 * SEMICONDUCTOR STANDARD SOFTWARE LICENSE AGREEMENT.
 *
 * Licensees are granted free, non-transferable use of the information. NO
 * WARRANTY of ANY KIND is provided. This heading must NOT be removed from
 * the file.
 *
 */

#ifndef NRF_DRV_CONFIG_H
#define NRF_DRV_CONFIG_H

/**
 * Provide a non-zero value here in applications that need to use several
 * peripherals with the same ID that are sharing certain resources
 * (for example, SPI0 and TWI0). Obviously, such peripherals cannot be used
 * simultaneously. Therefore, this definition allows to initialize the driver
 * for another peripheral from a given group only after the previously used one
 * is uninitialized. Normally, this is not possible, because interrupt handlers
 * are implemented in individual drivers.
 * This functionality requires a more complicated interrupt handling and driver
 * initialization, hence it is not always desirable to use it.
 */
#define PERIPHERAL_RESOURCE_SHARING_ENABLED  0

/* CLOCK */
#define CLOCK_ENABLED 0

#if (CLOCK_ENABLED == 1)
#define CLOCK_CONFIG_XTAL_FREQ          NRF_CLOCK_XTALFREQ_Default
#define CLOCK_CONFIG_LF_SRC             NRF_CLOCK_LF_SRC_Xtal
#define CLOCK_CONFIG_IRQ_PRIORITY       APP_IRQ_PRIORITY_LOW
#endif

/* GPIOTE */
#define GPIOTE_ENABLED 1

#if (GPIOTE_ENABLED == 1)
#define GPIOTE_CONFIG_USE_SWI_EGU false
#define GPIOTE_CONFIG_IRQ_PRIORITY APP_IRQ_PRIORITY_LOW
#define GPIOTE_CONFIG_NUM_OF_LOW_POWER_EVENTS 2
#endif

/* TIMER */
#define TIMER0_ENABLED 0

#if (TIMER0_ENABLED == 1)
#define TIMER0_CONFIG_FREQUENCY    NRF_TIMER_FREQ_16MHz
#define TIMER0_CONFIG_MODE         TIMER_MODE_MODE_Timer
#define TIMER0_CONFIG_BIT_WIDTH    TIMER_BITMODE_BITMODE_32Bit
#define TIMER0_CONFIG_IRQ_PRIORITY APP_IRQ_PRIORITY_LOW

#define TIMER0_INSTANCE_INDEX      0
#endif

#define TIMER1_ENABLED 0

#if (TIMER1_ENABLED == 1)
#define TIMER1_CONFIG_FREQUENCY    NRF_TIMER_FREQ_16MHz
#define TIMER1_CONFIG_MODE         TIMER_MODE_MODE_Timer
#define TIMER1_CONFIG_BIT_WIDTH    TIMER_BITMODE_BITMODE_16Bit
#define TIMER1_CONFIG_IRQ_PRIORITY APP_IRQ_PRIORITY_LOW

#define TIMER1_INSTANCE_INDEX      (TIMER0_ENABLED)
#endif

#define TIMER2_ENABLED 0

#if (TIMER2_ENABLED == 1)
#define TIMER2_CONFIG_FREQUENCY    NRF_TIMER_FREQ_16MHz
#define TIMER2_CONFIG_MODE         TIMER_MODE_MODE_Timer
#define TIMER2_CONFIG_BIT_WIDTH    TIMER_BITMODE_BITMODE_16Bit
#define TIMER2_CONFIG_IRQ_PRIORITY APP_IRQ_PRIORITY_LOW

#define TIMER2_INSTANCE_INDEX      (TIMER1_ENABLED+TIMER0_ENABLED)
#endif

#define TIMER3_ENABLED 0

#if (TIMER3_ENABLED == 1)
#define TIMER3_CONFIG_FREQUENCY    NRF_TIMER_FREQ_16MHz
#define TIMER3_CONFIG_MODE         TIMER_MODE_MODE_Timer
#define TIMER3_CONFIG_BIT_WIDTH    TIMER_BITMODE_BITMODE_16Bit
#define TIMER3_CONFIG_IRQ_PRIORITY APP_IRQ_PRIORITY_LOW

#define TIMER3_INSTANCE_INDEX      (TIMER2_ENABLED+TIMER1_ENABLED+TIMER0_ENABLED)
#endif

#define TIMER4_ENABLED 0

#if (TIMER4_ENABLED == 1)
#define TIMER4_CONFIG_FREQUENCY    NRF_TIMER_FREQ_16MHz
#define TIMER4_CONFIG_MODE         TIMER_MODE_MODE_Timer
#define TIMER4_CONFIG_BIT_WIDTH    TIMER_BITMODE_BITMODE_16Bit
#define TIMER4_CONFIG_IRQ_PRIORITY APP_IRQ_PRIORITY_LOW

#define TIMER4_INSTANCE_INDEX      (TIMER3_ENABLED+TIMER2_ENABLED+TIMER1_ENABLED+TIMER0_ENABLED)
#endif


#define TIMER_COUNT (TIMER0_ENABLED + TIMER1_ENABLED + TIMER2_ENABLED + TIMER3_ENABLED + TIMER4_ENABLED)

/* RTC */
#define RTC0_ENABLED 0

#if (RTC0_ENABLED == 1)
#define RTC0_CONFIG_FREQUENCY    32678
#define RTC0_CONFIG_IRQ_PRIORITY APP_IRQ_PRIORITY_LOW
#define RTC0_CONFIG_RELIABLE     false

#define RTC0_INSTANCE_INDEX      0
#endif

#define RTC1_ENABLED 0

#if (RTC1_ENABLED == 1)
#define RTC1_CONFIG_FREQUENCY    32768
#define RTC1_CONFIG_IRQ_PRIORITY APP_IRQ_PRIORITY_LOW
#define RTC1_CONFIG_RELIABLE     false

#define RTC1_INSTANCE_INDEX      (RTC0_ENABLED)
#endif

#define RTC_COUNT                (RTC0_ENABLED+RTC1_ENABLED)

#define NRF_MAXIMUM_LATENCY_US 2000

/* RNG */
#define RNG_ENABLED 1

#if (RNG_ENABLED == 1)
#define RNG_CONFIG_ERROR_CORRECTION true
#define RNG_CONFIG_POOL_SIZE        8
#define RNG_CONFIG_IRQ_PRIORITY     APP_IRQ_PRIORITY_LOW
#endif

/* PWM */

#define PWM0_ENABLED 0

#if (PWM0_ENABLED == 1)
#define PWM0_CONFIG_OUT0_PIN        2
#define PWM0_CONFIG_OUT1_PIN        3
#define PWM0_CONFIG_OUT2_PIN        4
#define PWM0_CONFIG_OUT3_PIN        5
#define PWM0_CONFIG_IRQ_PRIORITY    APP_IRQ_PRIORITY_LOW
#define PWM0_CONFIG_BASE_CLOCK      NRF_PWM_CLK_1MHz
#define PWM0_CONFIG_COUNT_MODE      NRF_PWM_MODE_UP
#define PWM0_CONFIG_TOP_VALUE       1000
#define PWM0_CONFIG_LOAD_MODE       NRF_PWM_LOAD_COMMON
#define PWM0_CONFIG_STEP_MODE       NRF_PWM_STEP_AUTO

#define PWM0_INSTANCE_INDEX 0
#endif

#define PWM1_ENABLED 0
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

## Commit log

2016-02-20 first pass on PCB
    [shoes.brd, shoes.sch, shoes_bom.xlsx]
2016-02-21 board changes
    added cap from power to ground
    [shoes.brd, shoes.sch]
2016-02-21 move antenna back
    [shoes.brd]
2016-02-23 update pcb
    [shoes.brd, shoes.sch]
2016-02-24 add files about pcb
    [shoes.sch, shoes_bom.csv]
2016-03-02 new PCB preliminary working
    [shoes.brd, shoes.sch]
2016-03-02 button works, lace LEDs work
2016-03-13 add costs to bom
    [shoes_bom.xlsx]
2016-05-10 added button press state machine
2016-05-11 delayed led
2016-05-13 fix TX range issue
    [main.c]

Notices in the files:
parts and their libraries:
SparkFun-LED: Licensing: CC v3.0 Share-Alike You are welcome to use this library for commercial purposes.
